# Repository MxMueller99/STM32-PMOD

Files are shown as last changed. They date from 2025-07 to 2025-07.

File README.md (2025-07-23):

# STM32-PMOD
A compact and cheap PMOD compatible **STM32G030K8T6** based PCB. 

# Demo

Demo

# Features
- Arm Cortex-M0+ MCU, 64 MHz CPU, 64 KB Flash, 8 KB RAM
- STM32 USART1 TX/RX routed to the PMOD connector (Pin 2 & 3)
- Two onboard programmable LEDs
- I2C interface pins (For displays or sensors)
- SWD Interface for debugging/flashing the STM32 

# Hardware Overview

## Schematic

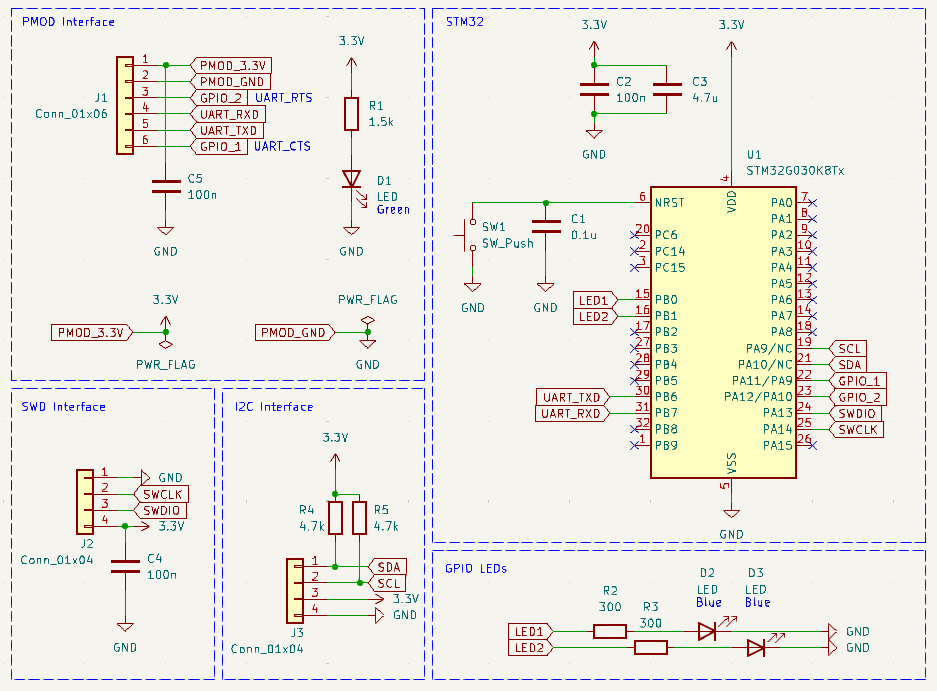
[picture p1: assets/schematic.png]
Schematic


## Layout

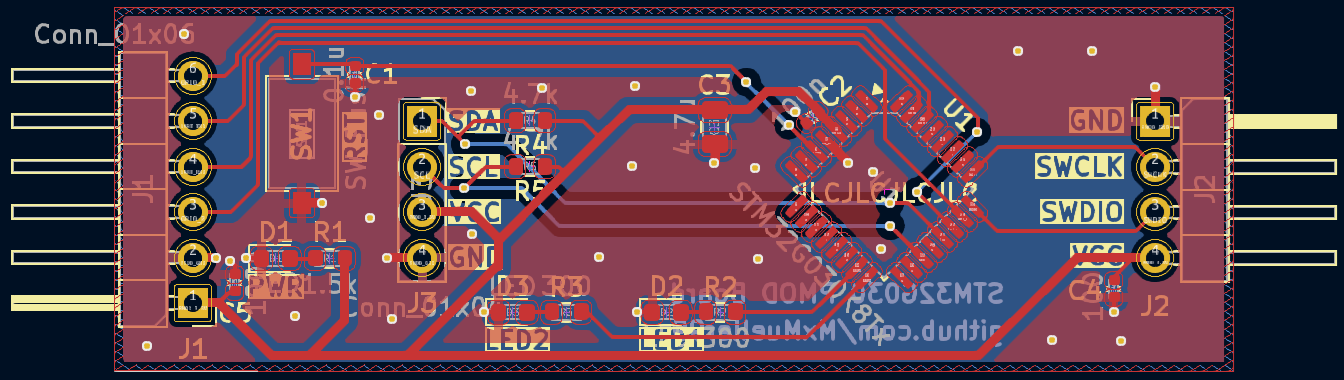
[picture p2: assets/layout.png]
Layout


## 3D Render

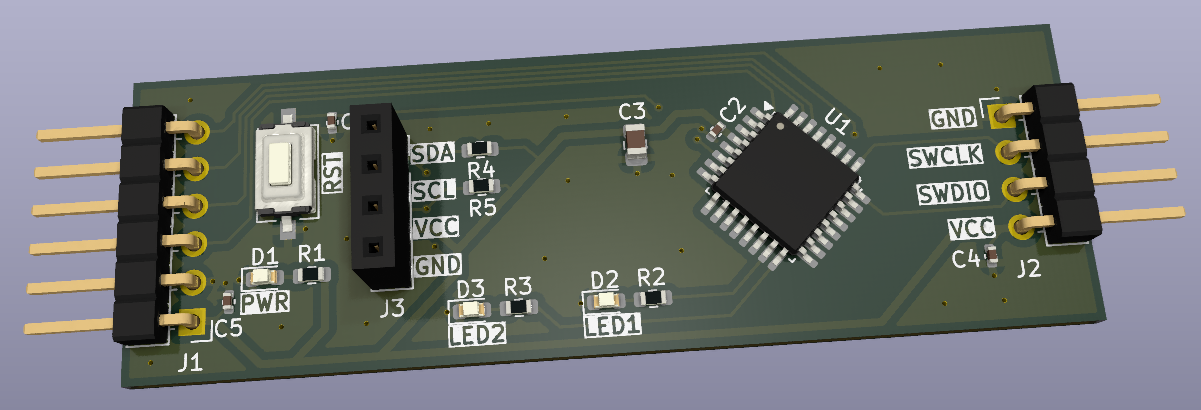
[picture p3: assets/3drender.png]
3D Render


# Example - UART Blink

A small example to demonstrate the UART capabilities between the Arty Z7-20 Zynq PS and the STM32G030 MCU located under: `/UART_Blink_Example/`

- FPGA: Sends a UART message periodically to the STM32
- STM32: Receives the UART message and toggles the LED
    - "LED1" blinks when receiving UART messages from the FPGA
    - "LED2" blinks as a heartbeat of the STM32

## Setup
1. Connect the PMOD board to the FPGA
2. Flash the STM32 example via the SWD pins
3. Program the FPGA and run the example in Vitis

The FPGA needs to have the UART enabled and the uart_tx pin routed to the PMOD connector pin 3.

# Example - UART OLED

Another example to display incoming UART messages from the FPGA to a small OLED display connected to the PMOD board.

UART_OLED

## Setup
Same as UART Blink

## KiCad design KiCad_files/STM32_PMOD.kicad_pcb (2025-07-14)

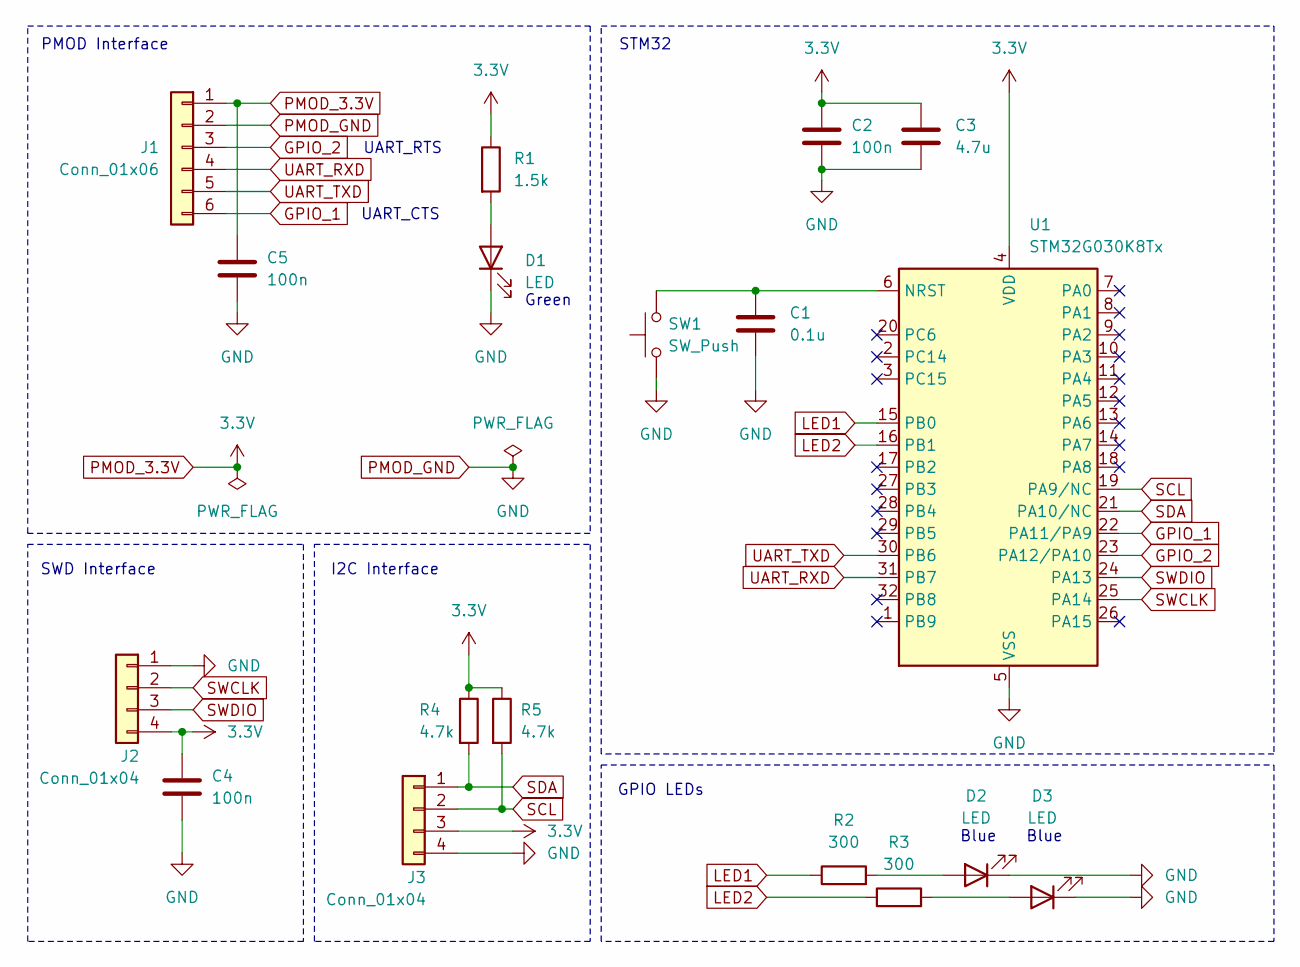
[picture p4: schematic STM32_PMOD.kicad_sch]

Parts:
C1: 0.1u; C_0402_1005Metric
C2, C4, C5: 100n; C_0402_1005Metric
C3: 4.7u; C_0805_2012Metric
D1, D2, D3: LED; LED_0603_1608Metric
J1: Conn_01x06; PinHeader_1x06_P2.54mm_Horizontal
J2: Conn_01x04; PinHeader_1x04_P2.54mm_Horizontal
J3: Conn_01x04; PinSocket_1x04_P2.54mm_Vertical
R1: 1.5k; R_0603_1608Metric
R2, R3: 300; R_0603_1608Metric
R4, R5: 4.7k; R_0603_1608Metric
SW1: SW_Push; SW_Tactile_SPST_NO_Straight_CK_PTS636Sx25SMTRLFS
U1: STM32G030K8Tx; LQFP-32_7x7mm_P0.8mm

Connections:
GPIO_1: J1.6, U1.22 (PA11/PA9)
GPIO_2: J1.3, U1.23 (PA12/PA10)
LED1: R2.1, U1.15 (PB0)
LED2: R3.1, U1.16 (PB1)
unnamed: D1.2 (A), R1.2
unnamed: D2.2 (A), R2.2
unnamed: D3.2 (A), R3.2
unnamed: C1.1, SW1.2, U1.6 (NRST)
PMOD_3.3V: C2.1, C3.1, C4.1, C5.1, J1.1, J2.4, J3.3, R1.1, R4.1, R5.1, U1.4 (VDD)
PMOD_GND: C1.2, C2.2, C3.2, C4.2, C5.2, D1.1 (K), D2.1 (K), D3.1 (K), J1.2, J2.1, J3.4, SW1.1, U1.5 (VSS)
SCL: J3.2, R5.2, U1.19 (PA9/NC)
SDA: J3.1, R4.2, U1.21 (PA10/NC)
SWCLK: J2.2, U1.25 (PA14)
SWDIO: J2.3, U1.24 (PA13)
UART_RXD: J1.4, U1.31 (PB7)
UART_TXD: J1.5, U1.30 (PB6)

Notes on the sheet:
GPIO LEDs
UART_RTS
PMOD Interface
Blue
UART_CTS
STM32
SWD Interface
Green
I2C Interface

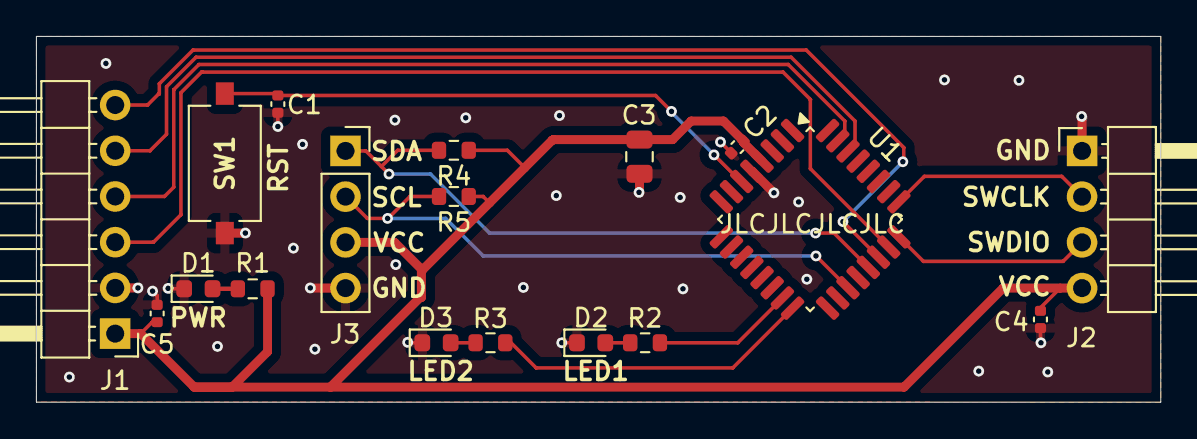
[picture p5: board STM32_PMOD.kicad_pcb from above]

Board: 2 copper layers, 62.5 x 20.3 mm, 18 parts (0 on the bottom side), 16 nets.

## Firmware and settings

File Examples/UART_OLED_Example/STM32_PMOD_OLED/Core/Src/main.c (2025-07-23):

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
/* Includes ------------------------------------------------------------------*/
#include "main.h"

/* USER CODE BEGIN Includes */
#include "ssd1306.h"	// SSD1306 I2C Display Driver
/* USER CODE END Includes */

I2C_HandleTypeDef hi2c1;

UART_HandleTypeDef huart1;

/* USER CODE BEGIN PV */
uint8_t rx_buffer[64];  // UART Byte Buffer
char text_buffer[64];   // Accumulate message
uint8_t idx = 0;
/* USER CODE END PV */

void SystemClock_Config(void);
static void MX_GPIO_Init(void);
static void MX_USART1_UART_Init(void);
static void MX_I2C1_Init(void);
/**
  * @brief  The application entry point.
  * @retval int
  */
int main(void)
{

  /* MCU Configuration--------------------------------------------------------*/

  /* Reset of all peripherals, Initializes the Flash interface and the Systick. */
  HAL_Init();

  /* Configure the system clock */
  SystemClock_Config();

  /* Initialize all configured peripherals */
  MX_GPIO_Init();
  MX_USART1_UART_Init();
  MX_I2C1_Init();
  /* USER CODE BEGIN 2 */
  HAL_NVIC_SetPriority(USART1_IRQn, 0, 0);
  HAL_NVIC_EnableIRQ(USART1_IRQn);

  HAL_UART_Receive_IT(&huart1, rx_buffer, 1); // Start receiving over interrupt

  ssd1306_init(&hi2c1);
  ssd1306_fill(0x00);  // Clear screen
  ssd1306_draw_string(0, 0, "Starting OLED...");
  ssd1306_update();
  /* USER CODE END 2 */

  /* Infinite loop */
  /* USER CODE BEGIN WHILE */
  while (1)
  {
	  HAL_GPIO_WritePin(GPIOB, GPIO_PIN_1, GPIO_PIN_SET);
	  HAL_Delay(100);
	  HAL_GPIO_WritePin(GPIOB, GPIO_PIN_1, GPIO_PIN_RESET);
	  HAL_Delay(900);
    /* USER CODE END WHILE */

    /* USER CODE BEGIN 3 */
  }
  /* USER CODE END 3 */
}

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
/* USER CODE BEGIN 4 */
void HAL_UART_RxCpltCallback(UART_HandleTypeDef *huart)
{
    if (huart->Instance == USART1) {
        // Blink LED
    	HAL_GPIO_TogglePin(GPIOB, GPIO_PIN_0);
        // Display Text
    	char received = rx_buffer[0];
    	 // Append received char to message
		if (received == '\r' || received == '\n') {
			if(idx > 0) {
				text_buffer[idx] = '\0';   								// terminate string

				ssd1306_fill(0x00);
				ssd1306_draw_string(0, 0, text_buffer);
				ssd1306_update();

				idx = 0;											// reset counter
			}
		} else if (idx < sizeof(text_buffer) - 1) {
			text_buffer[idx++] = received;
		}

        HAL_UART_Receive_IT(&huart1, rx_buffer, 1); 				// Restart RX
    }
}
/* USER CODE END 4 */
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


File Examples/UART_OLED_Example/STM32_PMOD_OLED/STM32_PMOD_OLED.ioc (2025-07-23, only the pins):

Mcu.UserName=STM32G030K8Tx
PA10.Signal=I2C1_SDA
PA13.Signal=SYS_SWDIO
PA14-BOOT0.Signal=SYS_SWCLK
PA9.Signal=I2C1_SCL
PB0.Signal=GPIO_Output
PB1.Signal=GPIO_Output
PB6.Signal=USART1_TX
PB7.Signal=USART1_RX

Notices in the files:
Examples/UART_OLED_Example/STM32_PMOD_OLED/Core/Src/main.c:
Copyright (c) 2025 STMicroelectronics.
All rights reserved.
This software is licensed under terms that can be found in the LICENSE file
